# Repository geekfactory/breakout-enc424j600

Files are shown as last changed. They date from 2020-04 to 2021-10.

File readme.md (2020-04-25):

# Breakout board for ENC424J600

This board implements a network interface based on the ENC424J600 Ethernet controller from Microchip Technology. All the required components to stablish an Ethernet link are contained in this board.

The signals required to communicate with a host processor are broken out to standard pitch headers. Status leds are provided to show the link and transmission status.

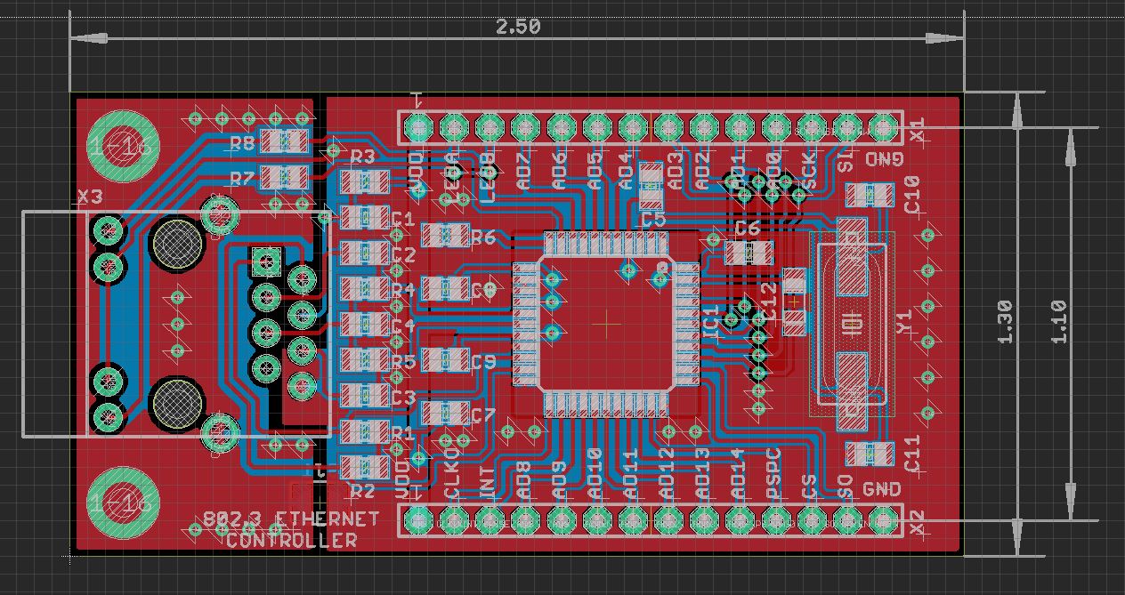
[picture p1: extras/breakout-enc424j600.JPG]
Breakout board for ENC424J600


## Features and hardware details

* On-board RJ-45 Jack with magnetics and ethernet controller (MAC and PHY layers)
* Small circuit footprint which fits solderless breadboards
* Requires 3.3 V power supply. No on-board regulation or level shifting provided
* Globally unique MAC address for easy deployment
* Standard header connections for easy prototyping on breadboards and protoboards

## Repository contents

1. __root__ - EAGLE Source files for the board
2. __/documents__ - Additional documentation, datasheets and assembly instructions
3. __/production__ - History of gerber files sent for production
4. __/extras__ - Technical drawings, mounting hardware and related accessories
4. __/firmware__ - Testing or definitive firmware for this board

## Hardware revisions

* 1.0 - First revision

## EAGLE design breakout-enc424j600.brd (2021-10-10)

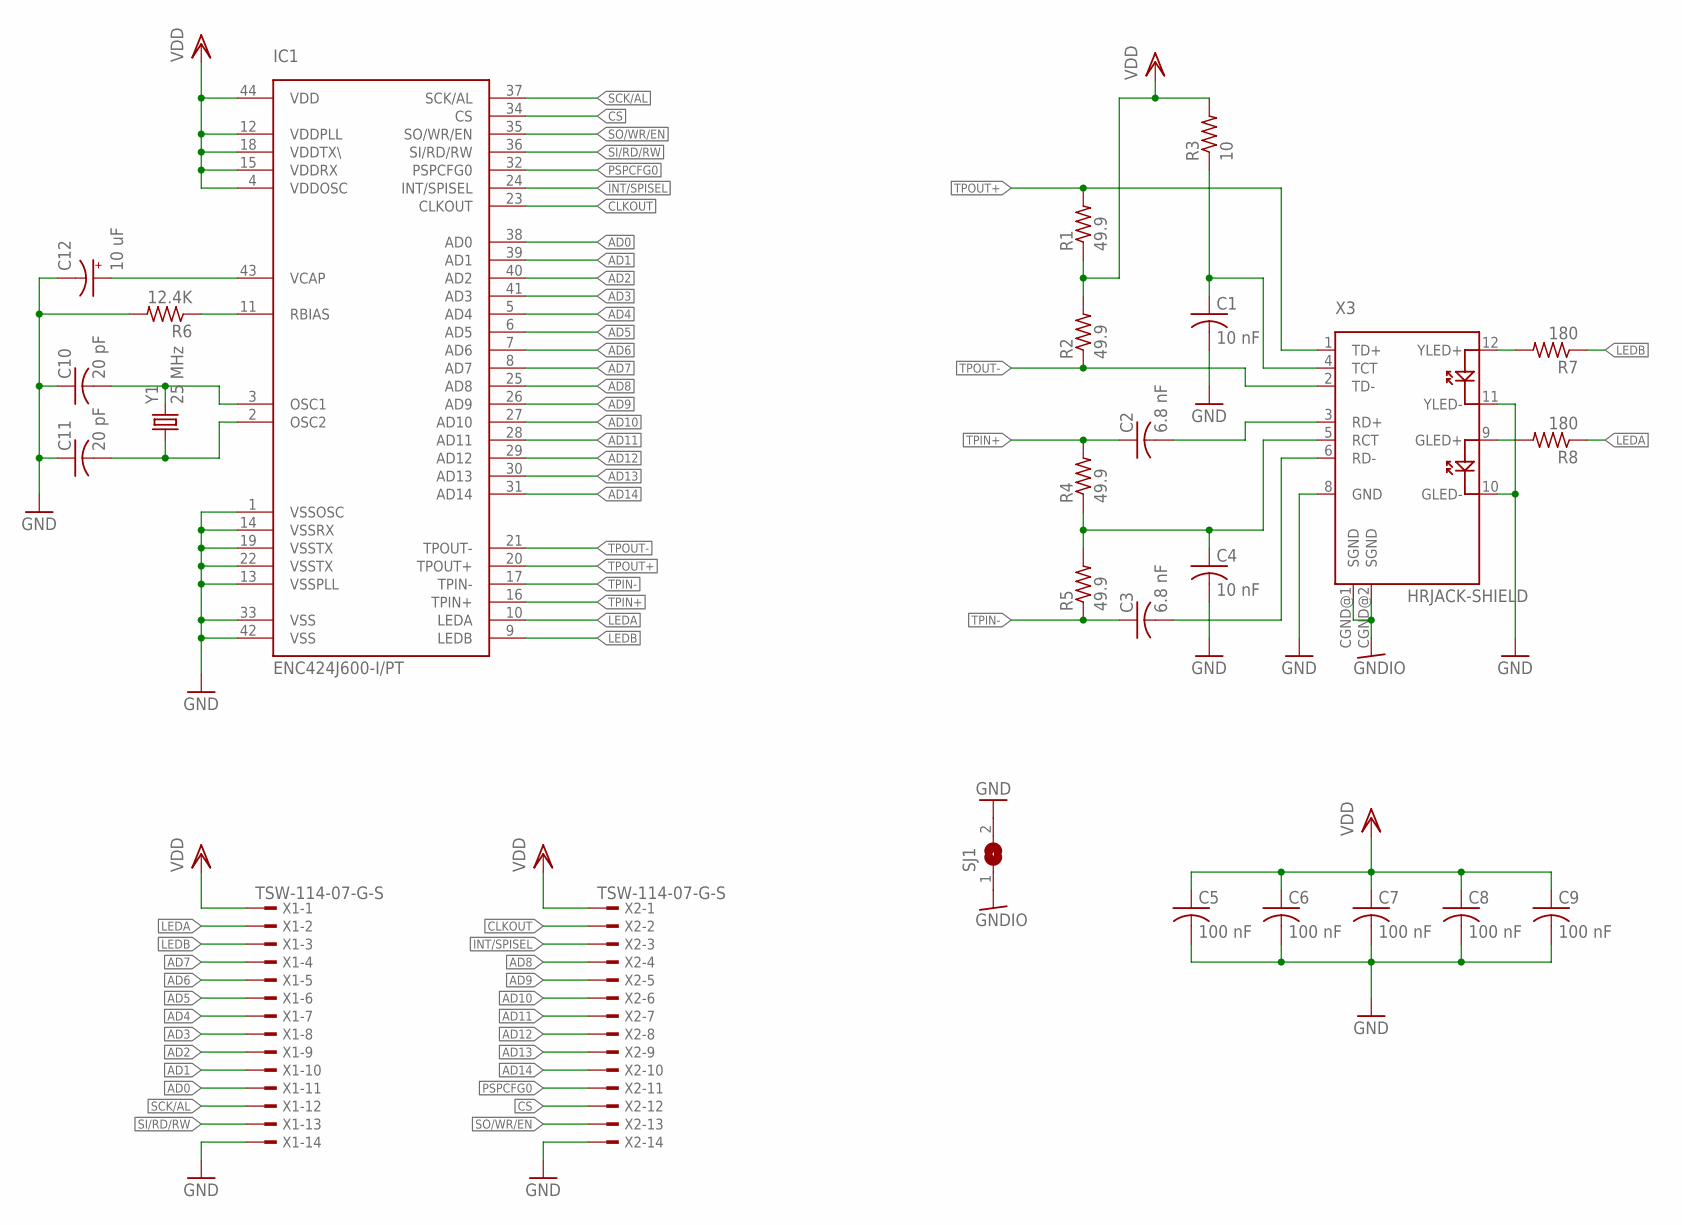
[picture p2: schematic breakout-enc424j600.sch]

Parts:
C1, C4: 10 nF; C0805
C2, C3: 6.8 nF; C0805
C5, C6, C7, C8, C9: 100 nF; C0805
C10, C11: 20 pF; C0805
C12: 10 uF; SMC_A
IC1: ENC424J600-I/PT; TQFP44
R1, R2, R4, R5: 49.9; R0805
R3: 10; R0805
R6: 12.4K; R0805
R7, R8: 180; R0805
SJ1: SJW
X1, X2: TSW-114-07-G-S; TSW-114-XX-G-S
X3: HRJACK-SHIELD; HR911105A
Y1: 25 MHz; HC49UP

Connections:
AD0: IC1.38 (AD0), X1.11
AD1: IC1.39 (AD1), X1.10
AD2: IC1.40 (AD2), X1.9
AD3: IC1.41 (AD3), X1.8
AD4: IC1.5 (AD4), X1.7
AD5: IC1.6 (AD5), X1.6
AD6: IC1.7 (AD6), X1.5
AD7: IC1.8 (AD7), X1.4
AD8: IC1.25 (AD8), X2.4
AD9: IC1.26 (AD9), X2.5
AD10: IC1.27 (AD10), X2.6
AD11: IC1.28 (AD11), X2.7
AD12: IC1.29 (AD12), X2.8
AD13: IC1.30 (AD13), X2.9
AD14: IC1.31 (AD14), X2.10
CLKOUT: IC1.23 (CLKOUT), X2.2
CS: IC1.34 (CS), X2.12
GND: C1.2, C4.2, C5.2, C6.2, C7.2, C8.2, C9.2, C10.1, C11.1, C12.-, IC1.1 (VSSOSC), IC1.13 (VSSPLL), IC1.14 (VSSRX), IC1.19 (VSSTX), IC1.22 (VSSTX), IC1.33 (VSS), IC1.42 (VSS), R6.2, SJ1.2, X1.14, X2.14, X3.8 (GND), X3.10 (GLED-), X3.11 (YLED-)
GNDIO: SJ1.1, X3.CGND@1 (SGND), X3.CGND@2 (SGND)
INT/SPISEL: IC1.24 (INT/SPISEL), X2.3
LEDA: IC1.10 (LEDA), R8.1, X1.2
LEDB: IC1.9 (LEDB), R7.1, X1.3
unnamed: C11.2, IC1.2 (OSC2), Y1.1
unnamed: C1.1, R3.1, X3.4 (TCT)
unnamed: C10.2, IC1.3 (OSC1), Y1.2
unnamed: C2.2, X3.3 (RD+)
unnamed: C3.2, X3.6 (RD-)
unnamed: C4.1, R4.1, R5.2, X3.5 (RCT)
unnamed: IC1.11 (RBIAS), R6.1
unnamed: R8.2, X3.9 (GLED+)
unnamed: R7.2, X3.12 (YLED+)
unnamed: C12.+, IC1.43 (VCAP)
PSPCFG0: IC1.32 (PSPCFG0), X2.11
SCK/AL: IC1.37 (SCK/AL), X1.12
SI/RD/RW: IC1.36 (SI/RD/RW), X1.13
SO/WR/EN: IC1.35 (SO/WR/EN), X2.13
TPIN+: C2.1, IC1.16 (TPIN+), R4.2
TPIN-: C3.1, IC1.17 (TPIN-), R5.1
TPOUT+: IC1.20 (TPOUT+), R1.2, X3.1 (TD+)
TPOUT-: IC1.21 (TPOUT-), R2.1, X3.2 (TD-)
VDD: C5.1, C6.1, C7.1, C8.1, C9.1, IC1.4 (VDDOSC), IC1.12 (VDDPLL), IC1.15 (VDDRX), IC1.18 (VDDTX\), IC1.44 (VDD), R1.1, R2.2, R3.2, X1.1, X2.1

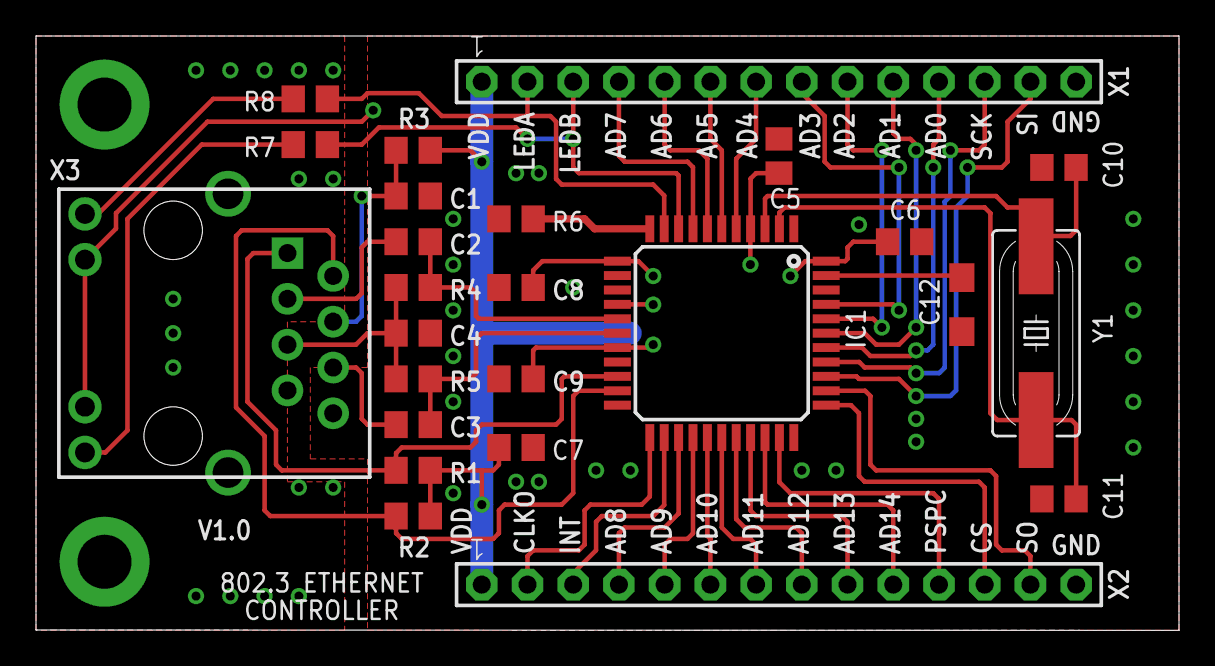
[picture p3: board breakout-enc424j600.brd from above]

Board: 2 copper layers, 63.5 x 33.0 mm, 26 parts (1 on the bottom side), 41 nets.

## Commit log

2020-04-25 Add pinout on silkscreen, change pin headers, connect ground shield on ethernet, modified board dimension
    [breakout-enc424j600.brd, breakout-enc424j600.sch]
2021-10-10 Add missing component values
    [breakout-enc424j600.brd, breakout-enc424j600.sch]
